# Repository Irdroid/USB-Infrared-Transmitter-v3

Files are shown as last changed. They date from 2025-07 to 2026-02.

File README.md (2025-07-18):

# Irdroid USB Infrared Transmitter v3

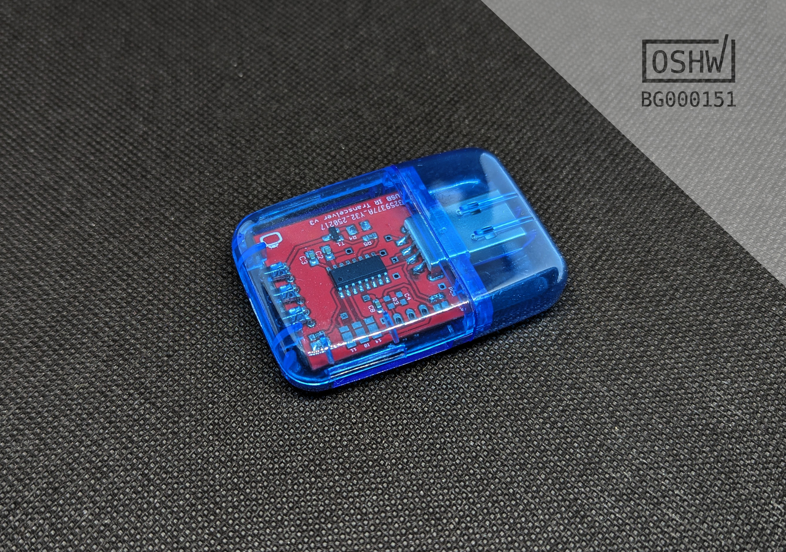
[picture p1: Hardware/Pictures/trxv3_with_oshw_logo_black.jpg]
USB Infrared Transmitter v3


The Irdroid USB Infrared transmitter device provides infrared remote control capabilities for the host computer. It is supported in Linux , MS Windows and Android. It is capable of controlling appliances such as TVs, STBs, Air Conditioners and basically any device that is controlled via infrared signals.
### Motivation
The first revisions of the Irdroid USB Infrared Transmitter product used Microchip's PIC18F2550 MCU.The increasing cost of this MCU and the limited availability of the MCU, after Covid/2020, demanded the commencement of this project.

### The search for a replacement MCU
During the development of this code a single piece of PIC18F2550 cost around 8USD. So hell-yeah that was a huge motivator.
The search for alternative microcontroller took place years before this project, but no viable candidate was found, until now. The requirements were met by a MCU manufactured by a Chineese company called WCH, and the selected MCU was CH552, a Harward architecture 89c51 core, with all the required peripherals. 
Last but not least, one pcs of the CH552 MCU costs 0.25 USD, providing similar features and performance, so voila...

### The Idea
- Design and implement a USB infrared transmitter adapter, that would be a drop-in replacement for the legacy Irdroid USB Infrared transmitter, without any re-design or re-work to the host drivers. With other words, we had to design and implement the firmware in such way, that the host could't differentiate the legacy and the new device. That turned out to be a challenging task. 
- Design and manufacture a printed circuit board for the new MCU, that would fit into the legacy enclosure, which would further reduce end product cost.
- Take care of the possibility for automatic flashing , during manufacture.
### The Challenges

- Significant differences between the two MCUs in terms of possibilities to configure the system clocks and clock dividers for the timer modules and the PWM module.
    - The Microchip's PIC18f2550, provides greater range of frequency division factors and it is a bit flexible in comparison with the WCH CH55x family of MCUs especially for the PWM module clock configuration.
    - There was a necessity to postprocess the IR data comming from the host to the WCH 552 MCU in order to re-align with its timer configuration for sending the RAW IR data
- Differences in the USB controller in both MCUs. Tweaking in software was required.
    - The implementation on the PIC18F2550 was done using polling the USB controller, rather than using interrupts.
    - The implementation on the CH552 was done using interrupts.
- Different development environment, no debugging capabilities
    - Microchip's PIC18F2550 has debugging support using a Pickit3 ICD adapter
    - The CH55x microcontrollers dont have hardware debugging support, thus in our case debugging was done with redirected printf on a small LCD screen. This is very innacurate in comparison with a hardware debugging support.
- Differences in flashing the firmware to the MCUs
    - The Microchip's PIC18F2550 uses PickIt 3 flash fromgrammers for flashing, they dont come with a bootloader, but pickit3 programmers has a very useful feature for in-field programming - no host required.
    - The WCH CH55x comes with a built in bootloader, which allows for flashing via USB or Serial interface.

### Software Development 

In terms of software, the idea was to re-use the code from the Irdroid USB Infrared Transmitter, which was written in C and port it to the new architecture. CH55x MCUs have a SDK with the SDCC compiler and it can be used with Visual Studio Code, which was our choise for the IDE. 

    - For this MCU there are no debugging capabilities, so we have connected an small i2c OLED display for brief debugging messages with printf.
    - The Saleae Logic analyzer was used also as a tool for debugging and measuring the IR signal output.

### Hardware Design

Due to the fact that we wanted to re-use the already available enclosure, which is used for the previous versions of the Irdroid USB Infrared Transmitter, we have designed the PCB with the same layout and size in order to fit the existing enclosure. For the design of the schematics and the pcb layout we have used EagleCad. A two sides single layer design with FR4 material. The newly designed adapter practically uses almost the same components as in the previous version, and even looks very similar 3 IR LEDs , same enclosure, same USB connector.

### CH552 Hardware
The MCU is 8-bit Harvard architecture 89c51 CPU, 256 bytes of fast RAM and a bit more
than 1k of slower xRam, 3 timer modules, 2 PWM modules, dataflash of 128 Bytes and a hardware USB 2.0 controller.
The above features and its price made it the perfect candidate for the project.

## CH552 SDK
The MCU could be programmed in C and it comes with a SDK (with some examples) for the SDCC compiler. The build system used is GNU Make.

## PURCHASE a SAMPLE UNIT
If you want to support us or you are interested in the product, purchase assembled and tested unit by clicking on the link below:
[Purchase a sample from Irdroid](https://irdroid.eu/product/usb-infrared-transmitter/)

Or purchase from Tindie:
[Purchase a sample from Tindie](https://www.tindie.com/products/irdroid/usb-infrared-transmitter-v3/)

## Instructions for usage of the code

    - Install the SDCC compiler on Linux - apt install sdcc
    - Install vscode and C/C++ plugins and Makefiles plugin for vscode
    - Clone this repository
    - Open a terminal , cd into the source code directory and type code .
    - When vscode loads open a terminal and type "make all", to compile the project
    - In order to flash the binary to the MCU , make sure the ch552 unit is in bootloader mode and type "make flash" in the terminal
    - To clean the project type "make clean"

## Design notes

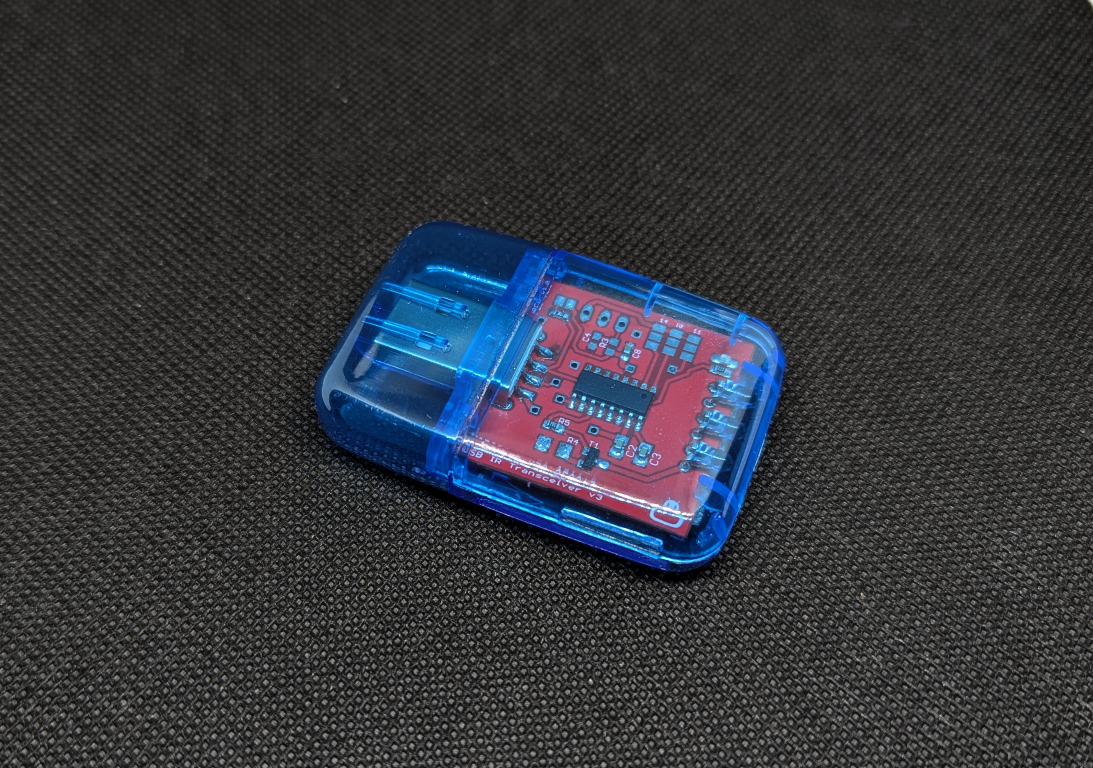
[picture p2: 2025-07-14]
Hardware/Pictures/black5 (Medium).png

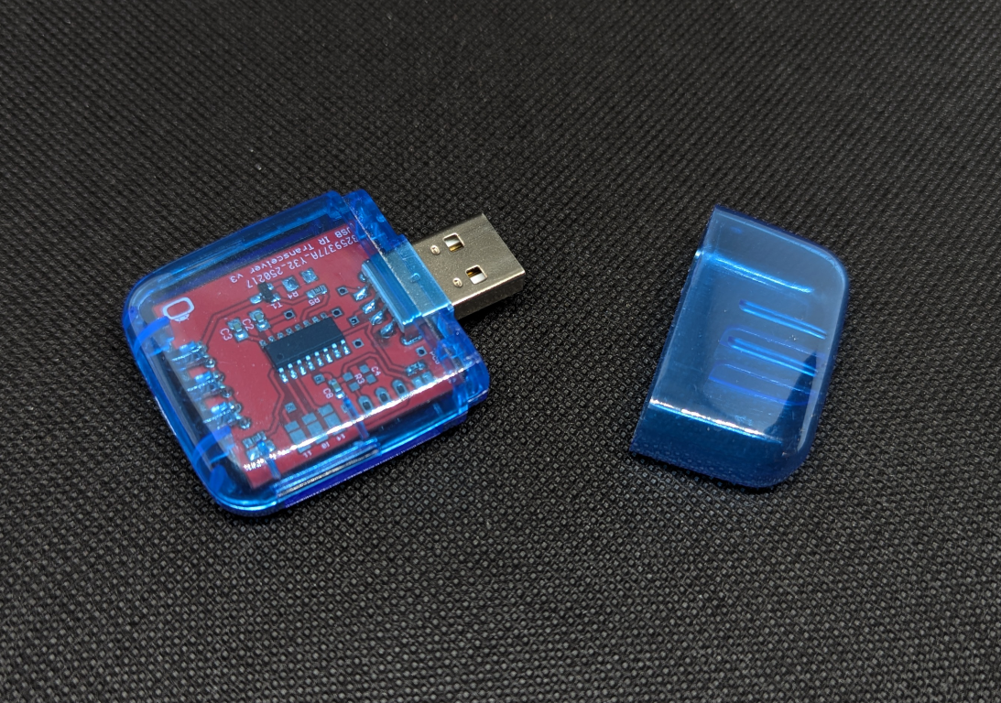
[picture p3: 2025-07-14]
Hardware/Pictures/black3 (Medium).png

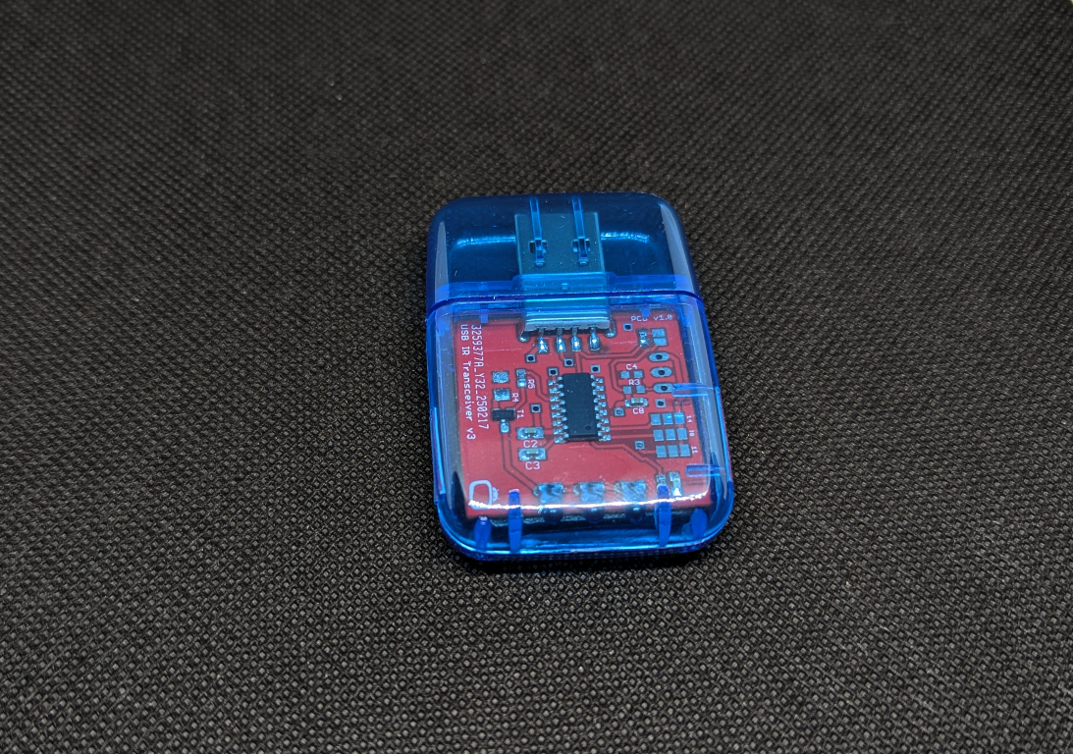
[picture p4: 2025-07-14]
Hardware/Pictures/black4 (Medium).png

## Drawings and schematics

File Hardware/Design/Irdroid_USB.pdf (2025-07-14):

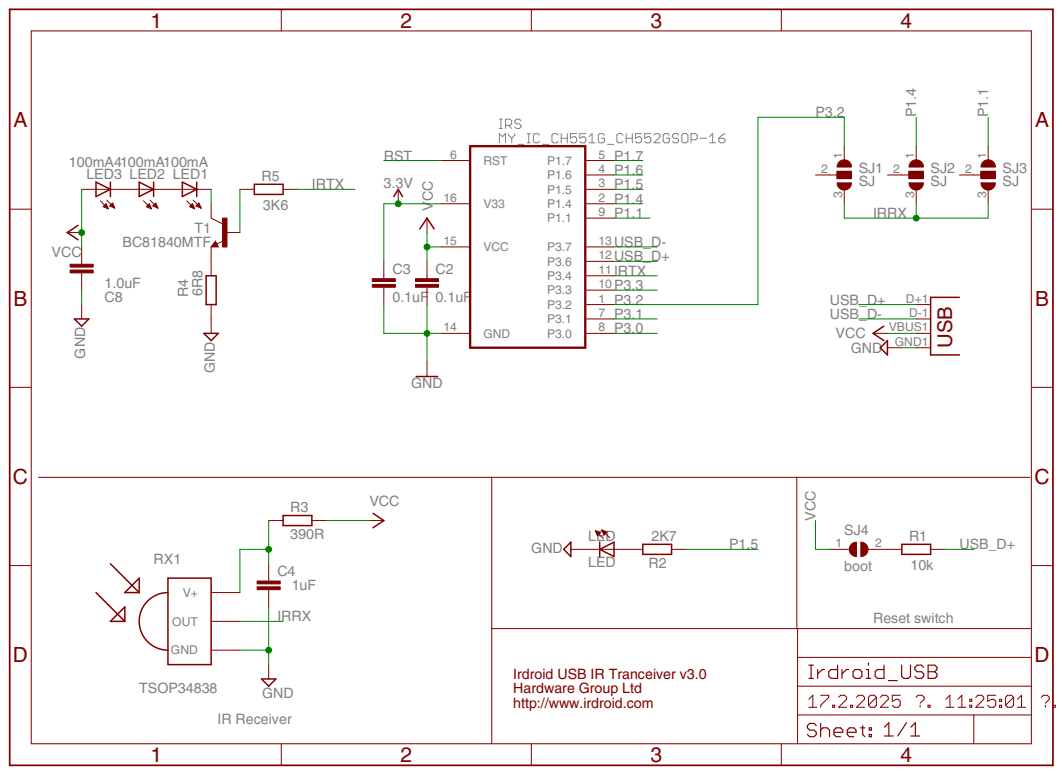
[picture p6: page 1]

Irdroid USB IR Tranceiver v3.0
Hardware Group Ltd
http://www.irdroid.com

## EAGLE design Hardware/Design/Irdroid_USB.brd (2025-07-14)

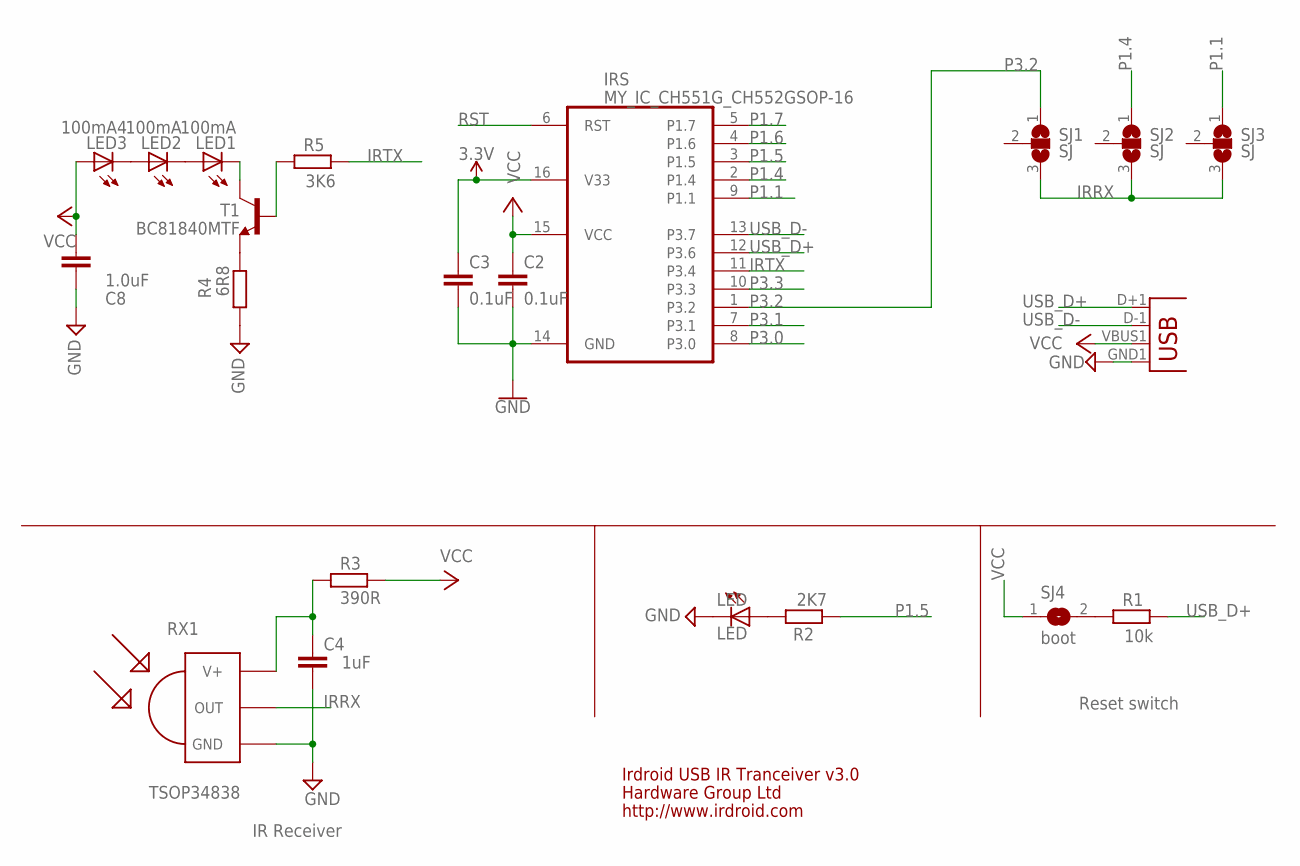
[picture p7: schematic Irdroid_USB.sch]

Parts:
C2, C3: 0.1uF; C0805K; LCSC C16834
C4: 1uF; C603
C8: 1.0uF; C603
IRS: MY_IC_CH551G_CH552GSOP-16; MY_IC_SO16; LCSC C111292
JP2: USBA-SMD-MALE; USB-A-SMT-MALE
LED: LED; CHIP-LED0805
LED1, LED2: 100mA; LED3MM
LED3: 100mA4; LED3MM
R1: 10k; R603
R2: 2K7; R603
R3: 390R; R603
R4: 6R8; M1206
R5: 3K6; R603
RX: TSOP34838; TSOP18XX
SJ1, SJ2, SJ3: SJ; SJ_2
SJ4: boot; SJ
T1: BC81840MTF; SOT23-BEC

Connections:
3.3V: C3.1, IRS.16 (V33)
GND: C2.2, C3.2, C4.2, C8.2, IRS.14 (GND), JP2.GND1 (GND), LED.C, R4.1, RX.GND
IRRX: RX.OUT, SJ1.3, SJ2.3, SJ3.3
IRTX: IRS.11 (P3.4), R5.2
unnamed: R1.1, SJ4.2
unnamed: LED1.A, LED2.K (C)
unnamed: LED2.A, LED3.K (C)
unnamed: R4.2, T1.E
unnamed: LED.A, R2.1
unnamed: C4.1, R3.1, RX.VCC (V+)
unnamed: R5.1, T1.B
unnamed: LED1.K (C), T1.C
P1.1: IRS.9 (P1.1), SJ3.1
P1.4: IRS.2 (P1.4), SJ2.1
P1.5: IRS.3 (P1.5), R2.2
P1.6: IRS.4 (P1.6)
P1.7: IRS.5 (P1.7)
P3.0: IRS.8 (P3.0)
P3.1: IRS.7 (P3.1)
P3.2: IRS.1 (P3.2), SJ1.1
P3.3: IRS.10 (P3.3)
RST: IRS.6 (RST)
USB_D+: IRS.12 (P3.6), JP2.D+1 (D+), R1.2
USB_D-: IRS.13 (P3.7), JP2.D-1 (D-)
VCC: C2.1, C8.1, IRS.15 (VCC), JP2.VBUS1 (VBUS), LED3.A, R3.2, SJ4.1

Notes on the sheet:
RX1
TSOP34838
Reset switch
IR Receiver
Hardware Group Ltd
Irdroid USB IR Tranceiver v3.0
http://www.irdroid.com

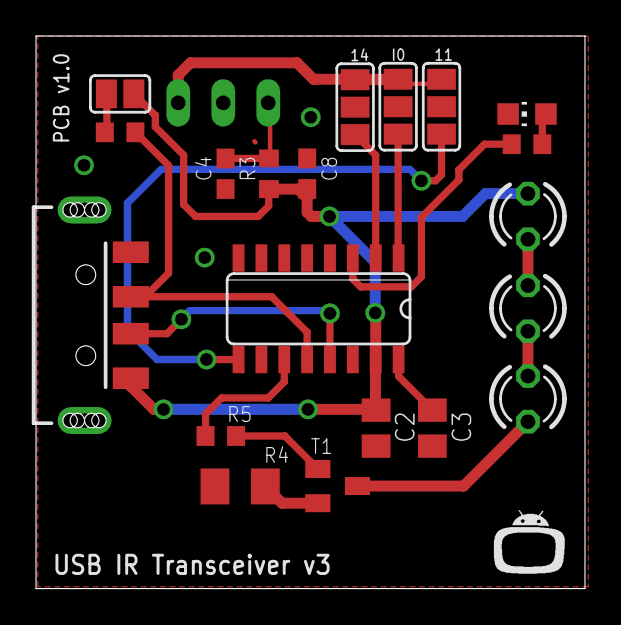
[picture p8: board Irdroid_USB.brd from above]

Board: 2 copper layers, 30.5 x 30.7 mm, 21 parts (1 on the bottom side), 19 nets.

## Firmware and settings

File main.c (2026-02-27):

// ===================================================================================
// Project:   Irdroid USB Infrared Transceiver for CH551, CH552, CH554
// Version:   v1.0
// Year:      2025
// Author:    Georgi Bakalski
// Github:    https://github.com/irdroid
// License:   http://creativecommons.org/licenses/by-sa/3.0/
// ===================================================================================
//
// Description:
// ------------
// This is a port of the Irdroid USB Infrared Tranceiver firmware from PIC18F2550 to 
// CH551, CH552, CH554
// References:
// -----------
// - Blinkinlabs: https://github.com/Blinkinlabs/ch554_sdcc

// Compilation Instructions:
// -------------------------
// - Chip:  CH551, CH552 or CH554
// - Clock: 24 MHz internal or external
// - Adjust the firmware parameters in src/config.h if necessary.
// - Make sure SDCC toolchain and Python3 with PyUSB is installed.
// - Press BOOT button on the board and keep it pressed while connecting it via USB
//   with your PC.
// - Run 'make flash' immediatly afterwards.
// - To compile the firmware using the Arduino IDE, follow the instructions in the 
//   .ino file.
// ===================================================================================
// Libraries, Definitions and Macros
// ===================================================================================

// Libraries
#include "src/config.h"                   // user configurations
#include "src/system.h"                   // system functions
#include "src/gpio.h"                     // for GPIO
#include "src/delay.h"                    // for delays
#include "src/usb_cdc.h"                  // for USB-CDC serial
#include "src/oled_term.h"                // for OLED
#include "src/irs.h"                      // IR sampling routines
#include "src/hwprofile.h"                // Hardware profile
#include "src/dataflash.h"
#include "usb_cdc.h"
#include "src/common.h"

#ifdef DEBUG
__xdata uint8_t dbg_buff[20];
#endif
extern uint8_t CDC_readPointer;     // data pointer for fetching
extern uint16_t target_freq;
/** References to the CDC in and out buffers */
register uint8_t * cdc_Out_buffer = (uint8_t *) EP2_buffer; 
register uint8_t * cdc_In_buffer = (uint8_t *) EP2_buffer+128; 
// Prototypes for used interrupts
void USB_interrupt(void);
void USB_ISR(void) __interrupt(INT_NO_USB) {
  USB_interrupt();
}
/** @brief Timer0 Interrupt routine */
void timer0_interrupt(void) __interrupt(INT_NO_TMR0)   
{ 
  timer0_int_callback(); 
}
/** @brief Timer1 Interrupt routine */
void timer1_interrupt(void) __interrupt(INT_NO_TMR1)   
{ 
  timer1_int_callback(); 
}
/** Timer 2 Interrupt Service Routine (Vector 5) */
void Timer2_ISR(void) __interrupt (INT_NO_TMR2) {
  timer2_int_callback(); 
}

/** The EXT0 pin and pin 1.1 are wire together with,
 *  the IR Receiver, so that we have a way to turn on Timer2 
 *  when we have a pin edge change
 */
void ext0_interrupt(void) __interrupt(INT_NO_INT0){
    ENABLE_TIMER2();
    cdc_In_buffer = inWhich(); 
}

static enum _mode {
    IR_MAIN = 0,
    IR_SUMP, //SUMP logic analyzer
    IR_S, //IR Sampling mode
} mode = IR_MAIN; //mode variable tracks the IR Toy mode

void SetUpDefaultMainMode(void) {
    mode = IR_MAIN; // Main mode
}

// ===================================================================================
// Main Function
// ===================================================================================
void main(void) {
  // Setup 
  CLK_config();                         // configure system clock
  DLY_ms(10);                           // wait for clock to stabilize
  CDC_init();                           // init the USB CDC  
  #ifdef DEBUG
  OLED_init();                          // Init the oled display/debugging  
  #endif
  SetUpDefaultMainMode();               // Setup default main mode
  PIN_low(PIN_PWM);
  
  /* This gives us information if we got a
   * command to jump to the bootloader */
  if(RST_wasWDT()){
    DBG("SW Reset");
    BOOT_now();
  }
   
/*
    * PWM registers configuration CH552
    * Fosc = 24000000 Hz
    * Fpwm = Fosc / 256 / PWM_CK_SE
    * Fpwm = 31.250 Hz (Requested : 38000 Hz)
    * Duty Cycle = 50 %
    * 
    * When using the hardware pwm module it seems, that
    * it is not possible to set the PWM carrier freq to
    * 38KHz, therefore this can be achieved using a timer,
    * and a GPIO pin, that way we can be more flexible setting
    * the correct PWM frequency
    * 
    * We have two options, one is the hardware PWM module,
    * the second is the implemented soft PWM, using timer 1.
    */ 
    //setup for IR RX
  #ifndef SOFT_PWM   
  PWM_CK_SE = 3;
  PIN_output(PIN_PWM); 
  // Bring the pwm pin off/IR LED off
  PIN_low(PIN_PWM); 
  // Setup the PWM Duty cycle to 50%
  PWM_write(PIN_PWM, PWM_DUTY_50);  
  #endif
  // configure the IRRX pin as input, pulled up (this is INT0 pin)
  PIN_input_PU(IRRX); 
  // Setup the timer0 Gated by Int0, when int0 becomes high, timer is started
  TMOD |= bT0_M0 | bT1_M0;   /* Run in time mode not counting */ 
  T2MOD = bT1_CLK; /* Divide the system clock by 12 */
  EA  = 1;     /* Enable global interrupt */
  EX0 = 1;    // Enable INT0
  /** INT0 is edge triggered */
  IT0 = 1;    // INT0 is edge triggered
  // Configure Timer 2 in Capture mode. FSYS/12 (2MHz)
  ConfigTimer2();
  // Just in case
  CDC_readPointer = 0;
  // Zero target frequency on startup
  target_freq = 0; 
  // Main loop
  while(1) {
    switch (mode)
    {
      case IR_S:
        if (irsService() != 0) SetUpDefaultMainMode();
        break;
      case IR_MAIN:
        if(CDC_available()) {  // something coming in?
          char byte = CDC_read_b(); // read the character ...  
          switch (byte)
          {
              case 'S': //Sampling Mode IR TX and IR RX
              case 's': 
                  irsSetup();
                  mode = IR_S;
                  break;
              case 'V':
              case 'v':// Acquire Version
                  GetUsbIrdroidVersion();
                  break;
              default:
                break;         
        }
        break;
      }
      default:
        break;
    }   
  }
}

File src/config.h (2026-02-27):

// ===================================================================================
// User configurations
// ===================================================================================

#pragma once

// Pin definitions
#define PIN_SDA             P16       // I2C SDA
#define PIN_SCL             P17       // I2C SCL
#define PIN_PWM             P34       // PWM pin
#define IRRX P32                      // IR Receive Pin
#define SOFT_PWM_MIN_PER    0.000000167F// minimum timer tick for soft PWM
#define SOFT_PWM
#define SPWM_DRIFT          35        // We observe 3us PWM Drift, this is correction constant
#define IRTOY_FREQ 48000000           // Irtoy Xtal frequency
#define IRTOY_MULTIPLIER 16           // Irtoy multiplier for the Xtal

#ifdef SOFT_PWM
#define PWM_FREQ            38000     // PWM Carrier is 38KHz
#else
#define PWM_FREQ            31250     // PWM Carrier is 31.25KHz 
#endif

// USB device descriptor
#define USB_VENDOR_ID       0x4d8     // VID Irdroid
#define USB_PRODUCT_ID      0xf58b   // PID Irdroid 
#define USB_DEVICE_VERSION  0x0300    // v1.0 (BCD-format)

// USB configuration descriptor
#define USB_MAX_POWER_mA    100       // max power in mA 

// USB descriptor strings
#define MANUFACTURER_STR    'H','a','r','d','w','a','r','e',' ','G','r','o','u','p',' ','L','T','D'
#define PRODUCT_STR         'U','S','B',' ','I','n','f','r','a','r','e','d',' ','T','r','a','n','s' \
                            ,'c','e','i','v','e','r'
#define SERIAL_STR          '3','5','2'
#define INTERFACE_STR       'C','D','C',' ','S','e','r','i','a','l'

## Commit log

2025-02-02 Updated device descriptors
2025-02-03 Added debugging switch in Makefile
2025-02-07 Switched to a 2MHz timer clock
2025-02-08 Timer 0 const is 43 0.000021333/(1/(FCPU/12))
2025-02-22 Fixed PWM frequency divider , wrong frequency
    [irs.c]
2025-02-22 Added Pwm_Configure function, part of the Soft PWM functionality
2025-02-24 Added soft pwm functionality using timer 1; TODO: test the solution
2025-02-24 First tests with the Soft PWM implementation fixed the timer1 calculation formula and added a drift constant
    [config.h, irs.c]
2025-02-25 Soft PWM functionality tested. working!
2025-02-25 Fixed the blocking CDC read in irs.c, this is needed if we want to support reception at the same time
    [irs.c, irs.h]
2025-02-26 Irdroid USB Infrared Transmitter with hardware and software PWM
2025-03-05 Ledoff on power-up, PWM pin low on boot
2025-03-05 Led off upon enumeration
2025-03-06 Fixed the locking issue, that occur when winlirc exits, the unit remains in sampling mode and if winlirc is started again in locks
    [irs.c]
2025-03-08 Updated version in Serial STR; updated pid/ Irdroid pid is 0xf58b
2025-03-22 Fixed the failed to send START TX command in Linux, optimised the ir sampling routine; fixed stability issues; regression tests ongoing
    [irs.c]
2025-04-23 Fixed initial enumeration issues in Linux
    [main.c]
2025-07-14 Irdroid USB Infrared transmitter is now open source software and hardware
    [Irdroid_USB.brd, Irdroid_USB.sch]
2026-01-22 Switched to fast timer0/2 for testing
2026-02-11 Implemented IR Reception
    Implemented GAP measurement and reporting
    Tested with Winlirc
    Tested Transmission and Reception with WinLirc
    Code formatting, fix ConfigTimer1 function
    updated version
    [config.h, irs.c, irs.h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]
2026-02-27 Fixed a bug, related to the configuration of the SoftPWM carrier frequency
    [config.h, irs.c, irs.h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]

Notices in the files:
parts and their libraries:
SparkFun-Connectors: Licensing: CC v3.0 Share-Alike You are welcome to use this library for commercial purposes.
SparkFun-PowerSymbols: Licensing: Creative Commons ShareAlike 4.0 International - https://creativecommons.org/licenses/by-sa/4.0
